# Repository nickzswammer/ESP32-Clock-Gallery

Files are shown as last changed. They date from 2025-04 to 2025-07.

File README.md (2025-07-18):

ESP32

8Ul8SPUI

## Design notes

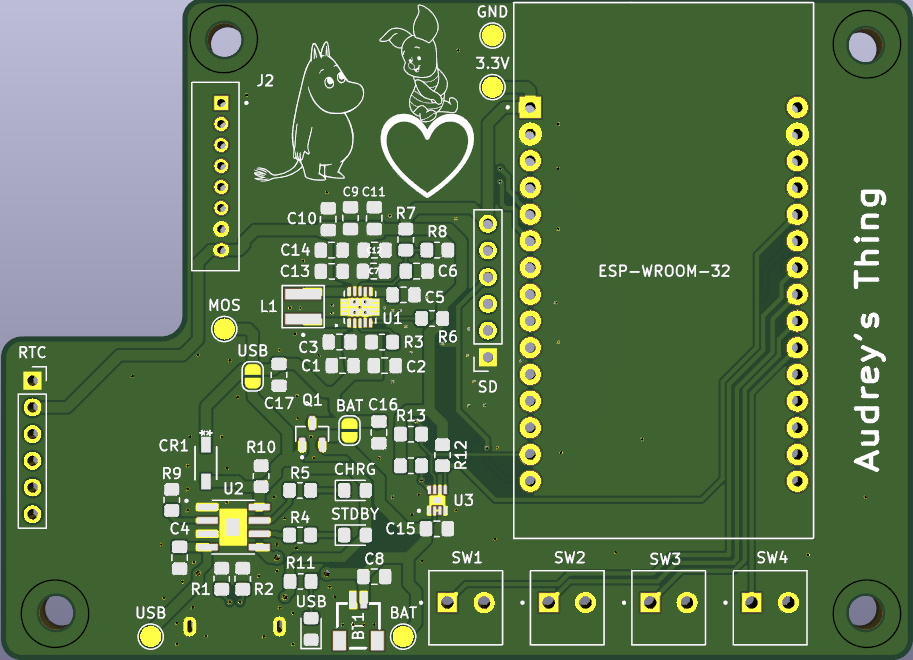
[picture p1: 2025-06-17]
PCB/enclosure/ESP32_Clock_Gallery_topsilkscreen.png

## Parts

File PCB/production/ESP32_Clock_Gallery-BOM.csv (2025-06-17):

Reference | Value | Datasheet | Footprint | Qty | DNP
BT1 | 3.7V 1500mAh LiPo | ~ | SM02B-SRSS-TB_LF__SN_:SM02B-SRSS-TB_LF__SN_ | 1
C1,C2,C4,C8,C9,C10,C11,C12,C13,C14,C16,C17 | 10uF | ~ | Capacitor_SMD:C_0805_2012Metric_Pad1.18x1.45mm_HandSolder | 12
C3,C5,C7,C15 | 0.1uF | ~ | Capacitor_SMD:C_0805_2012Metric_Pad1.18x1.45mm_HandSolder | 4
C6 | 2.2pF | ~ | Capacitor_SMD:C_0805_2012Metric_Pad1.18x1.45mm_HandSolder | 1
CR1 | B5819W-TP | B5819W-TP | B5819SW:SDO_SOD-123_MCC-M | 1
D1,D2,D3 | LED | ~ | LED_SMD:LED_0805_2012Metric_Pad1.15x1.40mm_HandSolder | 3
J1 | UJC-V-G-SMT-P6-TR |  | UJC_V_G_SMT_P6_TR:SAMESKY_UJC-V-G-SMT-P6-TR | 1
J2 | B8B-PH-K-S_LF__SN_ |  | B8B-PH-K-S_LF__SN_:JST_B8B-PH-K-S_LF__SN_ | 1
L1 | 1.2 uH | ~ | XFL4020-102MEC:IND_XFL4020-102MEC | 1
Q1 | PMOS |  | IRLML6402TRPBF:SOT95P237X112-3N | 1
R1,R2 | 5.1K | ~ | Resistor_SMD:R_0805_2012Metric_Pad1.20x1.40mm_HandSolder | 2
R3,R6 | 100K | ~ | Resistor_SMD:R_0805_2012Metric_Pad1.20x1.40mm_HandSolder | 2
R4,R5 | 1K | ~ | Resistor_SMD:R_0805_2012Metric_Pad1.20x1.40mm_HandSolder | 2
R7 | 360K | ~ | Resistor_SMD:R_0805_2012Metric_Pad1.20x1.40mm_HandSolder | 1
R8 | 64.9K | ~ | Resistor_SMD:R_0805_2012Metric_Pad1.20x1.40mm_HandSolder | 1
R9 | 1.5K | ~ | Resistor_SMD:R_0805_2012Metric_Pad1.20x1.40mm_HandSolder | 1
R10,R12 | 10K | ~ | Resistor_SMD:R_0805_2012Metric_Pad1.20x1.40mm_HandSolder | 2
R11 | 470 | ~ | Resistor_SMD:R_0805_2012Metric_Pad1.20x1.40mm_HandSolder | 1
R13,R14 | 4.7K | ~ | Resistor_SMD:R_0805_2012Metric_Pad1.20x1.40mm_HandSolder | 2
SW1,SW2,SW3,SW4 | DB301V-3.5-2P-GN-S | ~ | 1984617:PHOENIX_1984617 | 4
TP1,TP2,TP3,TP4,TP5 | TestPoint | ~ | TestPoint:TestPoint_Pad_D2.0mm | 5
U1 | TPS63060 | http://www.ti.com/lit/ds/symlink/tps63060.pdf | TPS63060DSCT:CONV_TPS63060DSCT | 1
U2 | TP4056 |  | TP4056:SOP127P600X175-9N | 1
U3 | MAX17048G_T10 |  | MAX17048G_T10:SON50P200X200X80-9N | 1
U4 | DS3231 Breakout |  | Connector_PinSocket_2.54mm:PinSocket_1x06_P2.54mm_Vertical | 1
U5 | MicroSD Breakout |  | Connector_PinSocket_2.54mm:PinSocket_1x06_P2.54mm_Vertical | 1
U6 | ESP-WROOM-32 Dev Module |  | ESP32-DEVKIT-V1:MODULE_ESP32_DEVKIT_V1 | 1

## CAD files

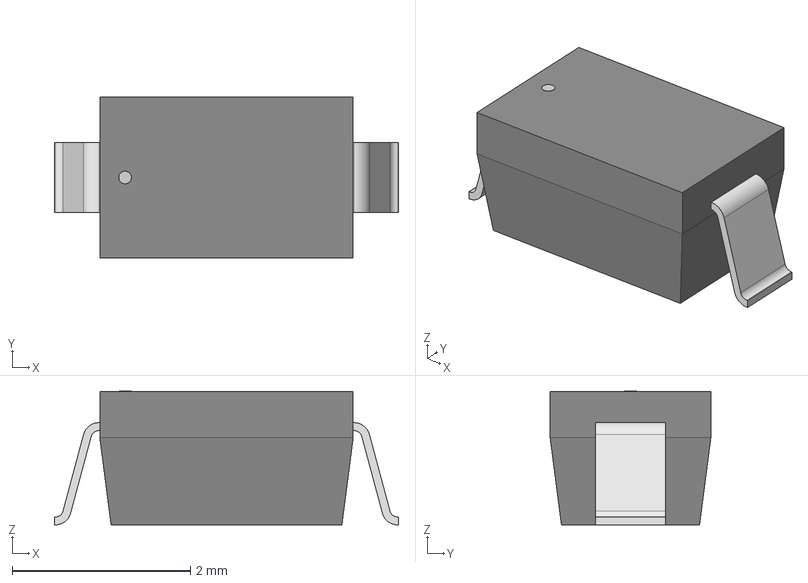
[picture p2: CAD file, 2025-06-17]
PCB/3dmodels/SDO_SOD-123_MCC.step
3.86 x 1.80 x 1.50 mm

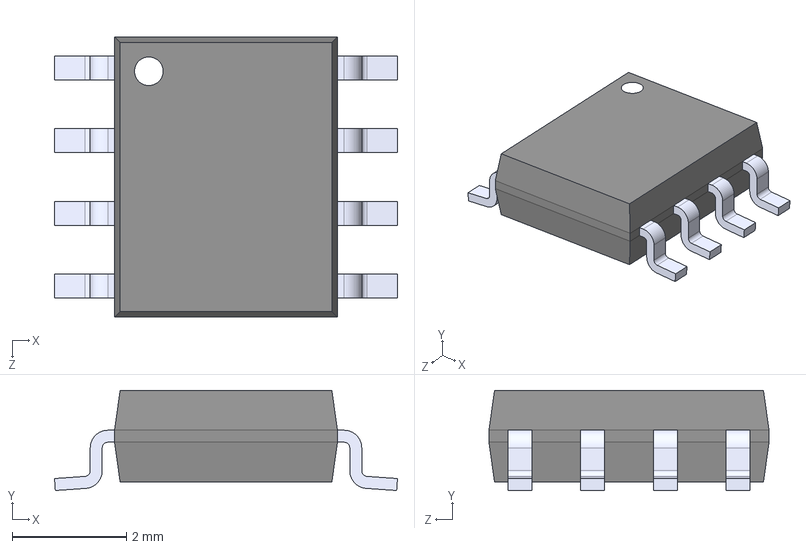
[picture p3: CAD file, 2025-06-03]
PCB/Components/TP4056/TP4056.step
6.00 x 1.75 x 4.90 mm

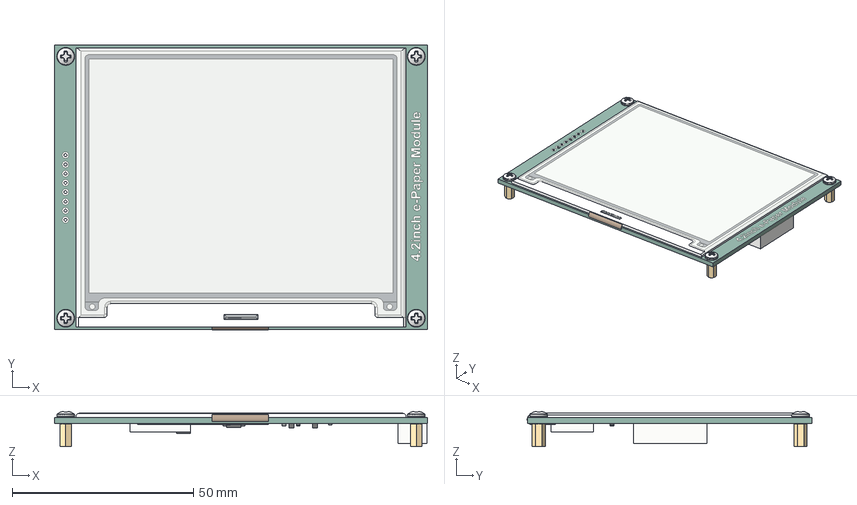
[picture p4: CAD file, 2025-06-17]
PCB/enclosure/Waveshare 4.2inch e-Paper Module.step
103.0 x 78.6 x 9.79 mm
Waveshare 4.2 E-Ink - Display folded cable
PCB
90268A201 x 4
91772A030 x 4

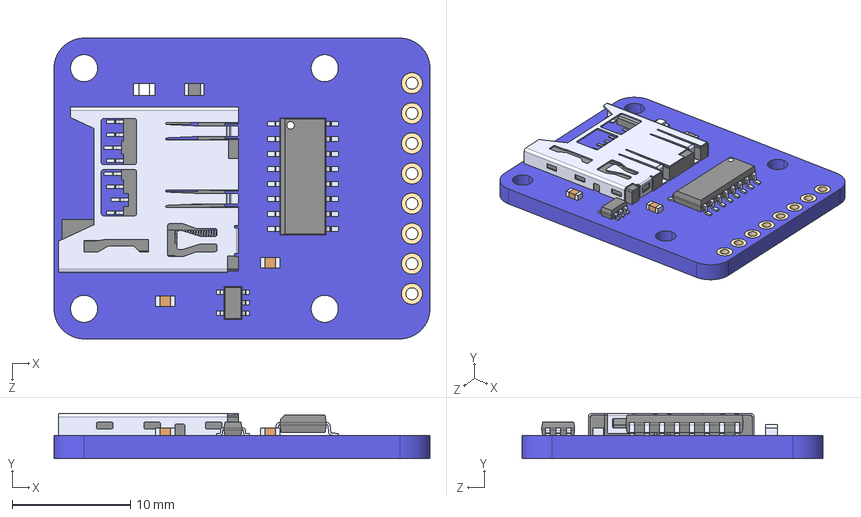
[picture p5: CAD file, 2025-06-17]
PCB/3dmodels/ada_microSD.STEP
31.8 x 3.81 x 25.4 mm

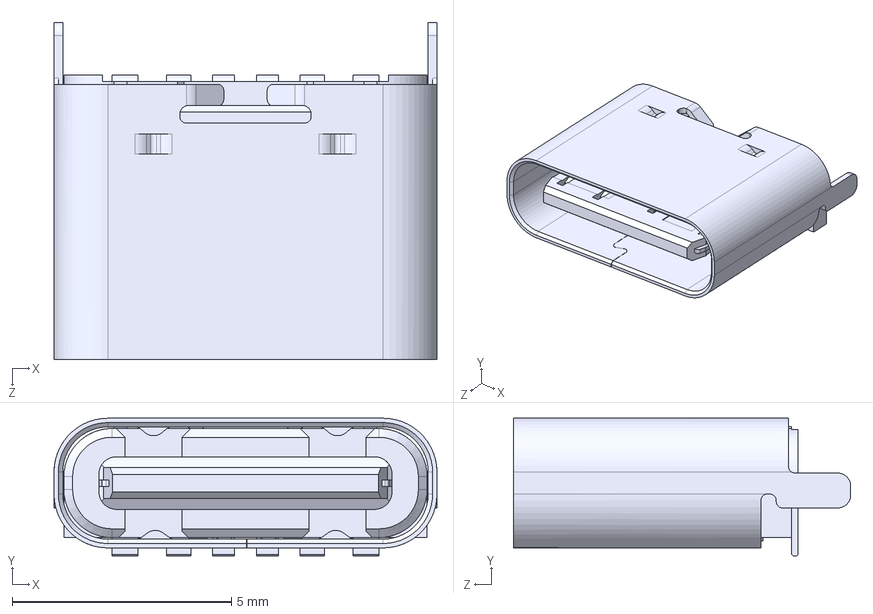
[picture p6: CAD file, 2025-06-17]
PCB/3dmodels/Same_Sky_UJC-V-G-SMT-P6-TR.step
8.74 x 3.14 x 7.70 mm

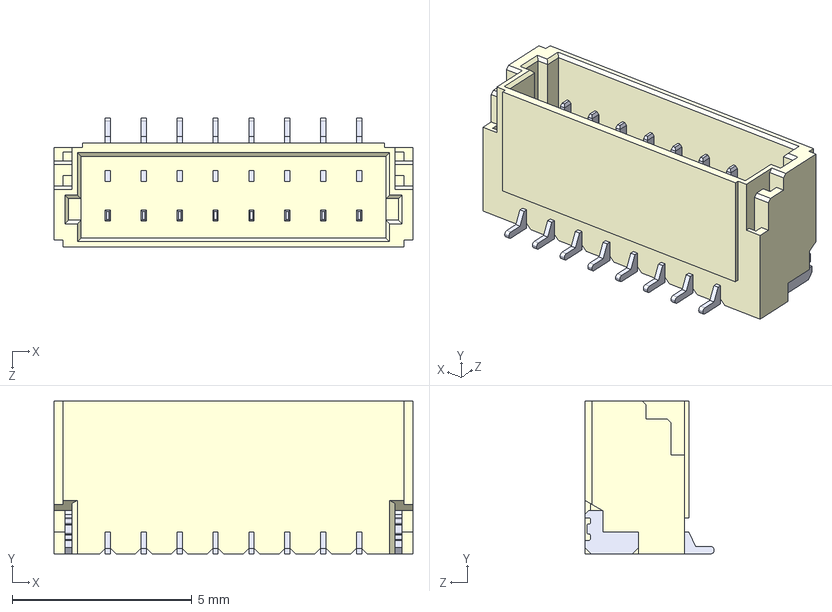
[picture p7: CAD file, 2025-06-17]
PCB/3dmodels/BM08B-SRSS-TB-LF--SN---3DModel-STEP-269445.STEP
10.0 x 4.25 x 3.60 mm

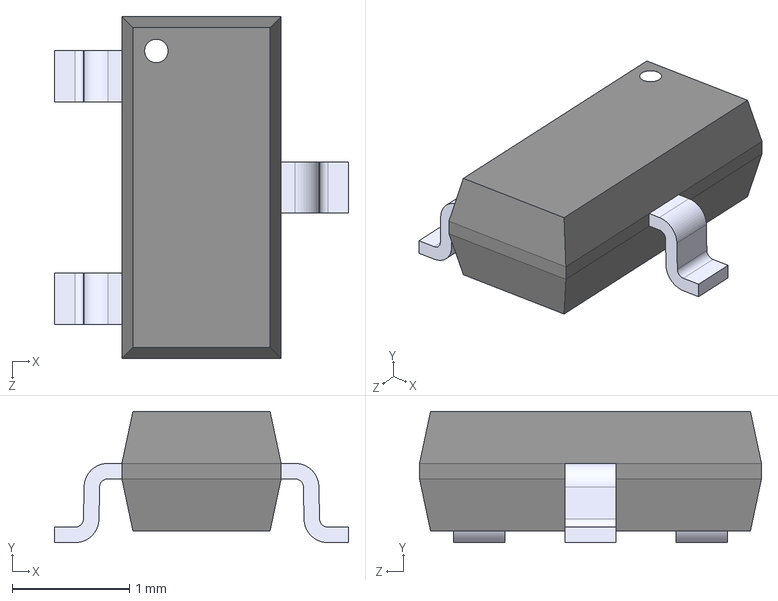
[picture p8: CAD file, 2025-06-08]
PCB/3dmodels/IRLML6402TRPBF.step
2.51 x 1.12 x 2.92 mm

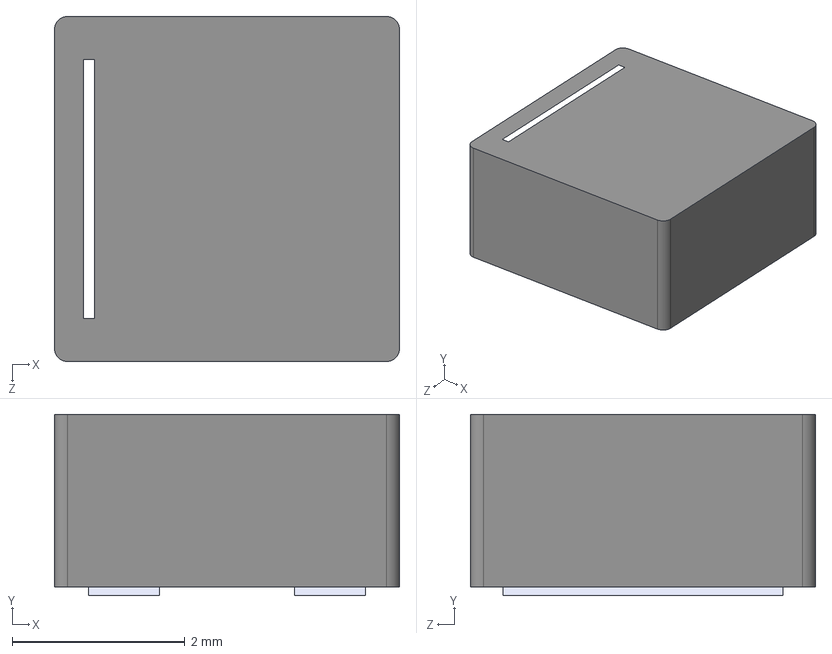
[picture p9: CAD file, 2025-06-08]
PCB/3dmodels/XFL4020-102MEC--3DModel-STEP-269445.STEP
4.00 x 2.10 x 4.00 mm

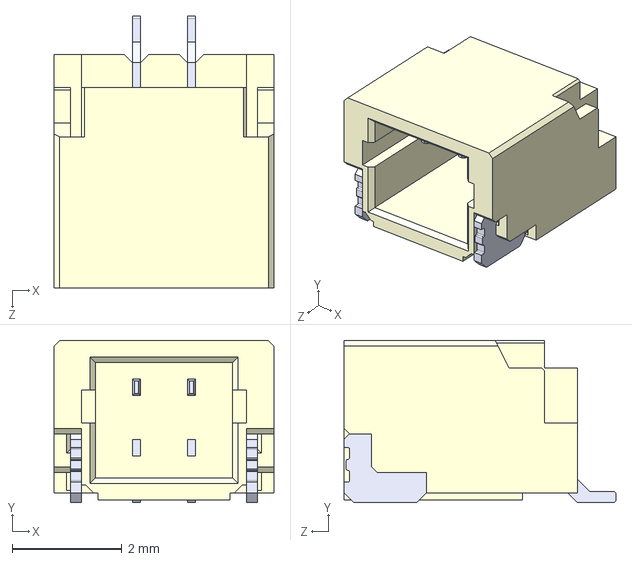
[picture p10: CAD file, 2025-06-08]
PCB/3dmodels/SM02B-SRSS-TB-LF--SN---3DModel-STEP-56544.STEP
4.00 x 2.95 x 4.95 mm

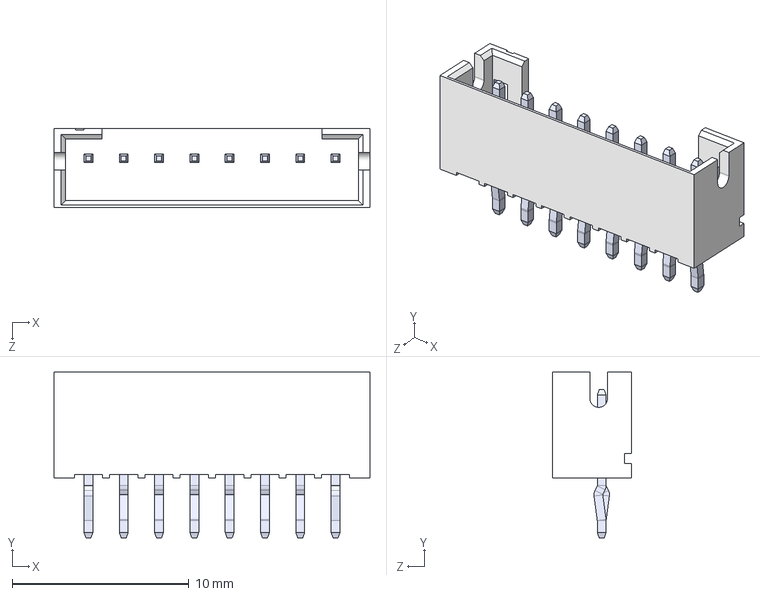
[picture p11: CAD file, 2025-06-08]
PCB/3dmodels/B8B-PH-K-S-LF--SN---3DModel-STEP-56544.STEP
17.9 x 9.40 x 4.50 mm

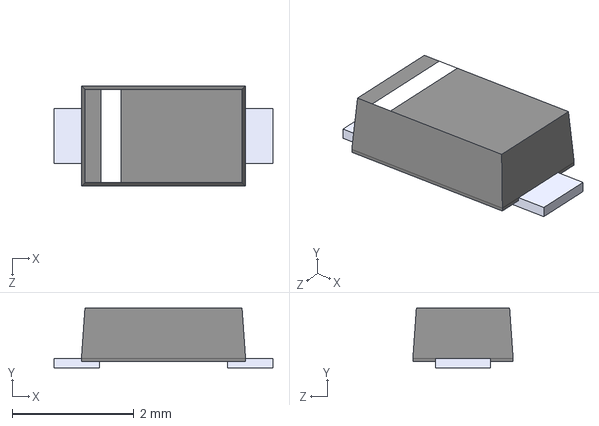
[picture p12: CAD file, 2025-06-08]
PCB/3dmodels/MBR120VLSFT1G.step
3.60 x 0.98 x 1.65 mm

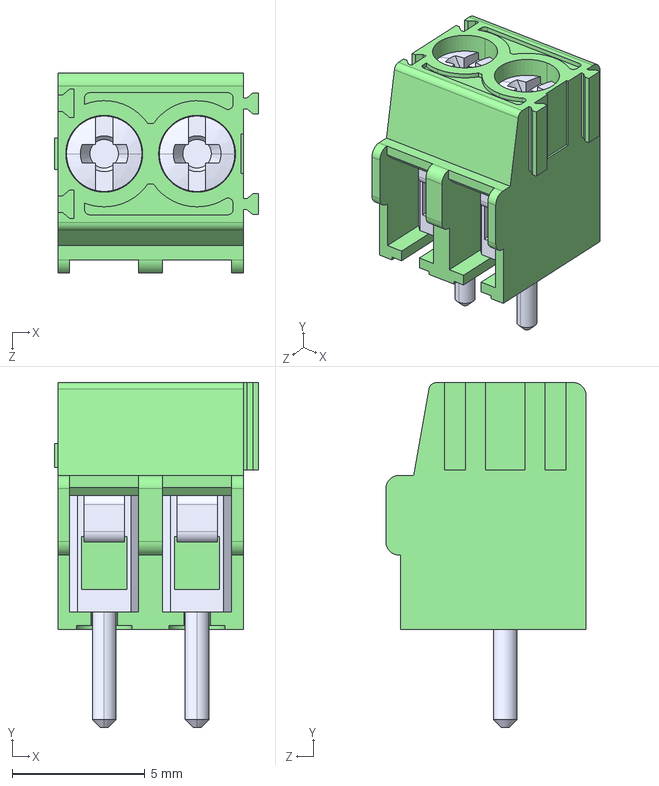
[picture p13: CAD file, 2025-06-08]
PCB/Components/1984617/1984617.step
7.70 x 13.0 x 7.55 mm

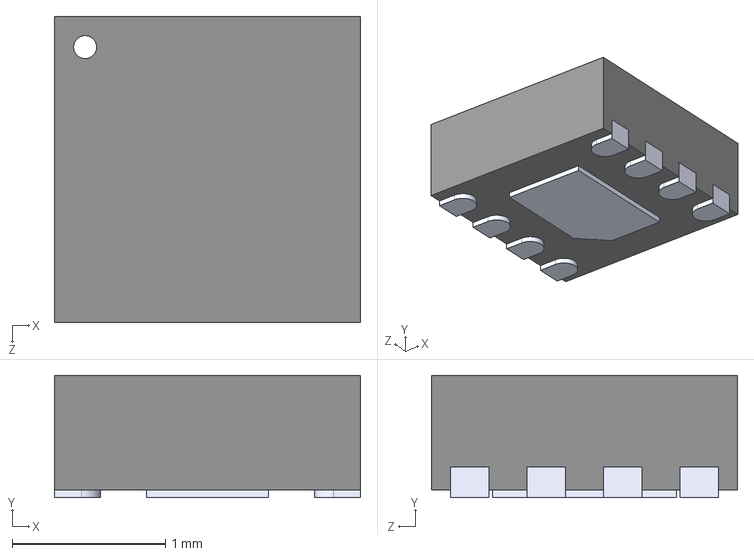
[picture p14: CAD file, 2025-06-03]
PCB/Components/MAX17048G_T10/MAX17048G_T10.step
2.00 x 0.8 x 2.00 mm

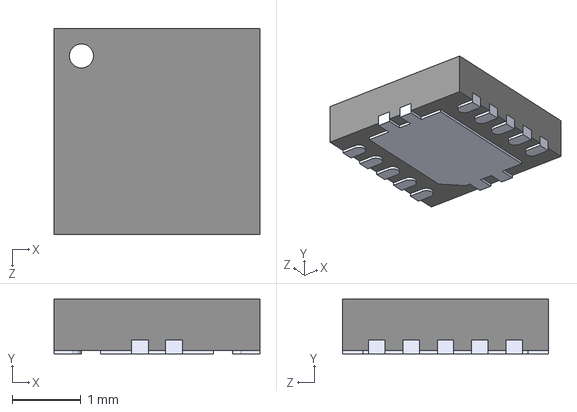
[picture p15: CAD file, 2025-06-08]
PCB/3dmodels/TPS63060DSCT.STEP
3.00 x 0.8 x 3.00 mm

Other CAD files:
PCB/3dmodels/XAL4020122ME--3DModel-STEP-56544.STEP

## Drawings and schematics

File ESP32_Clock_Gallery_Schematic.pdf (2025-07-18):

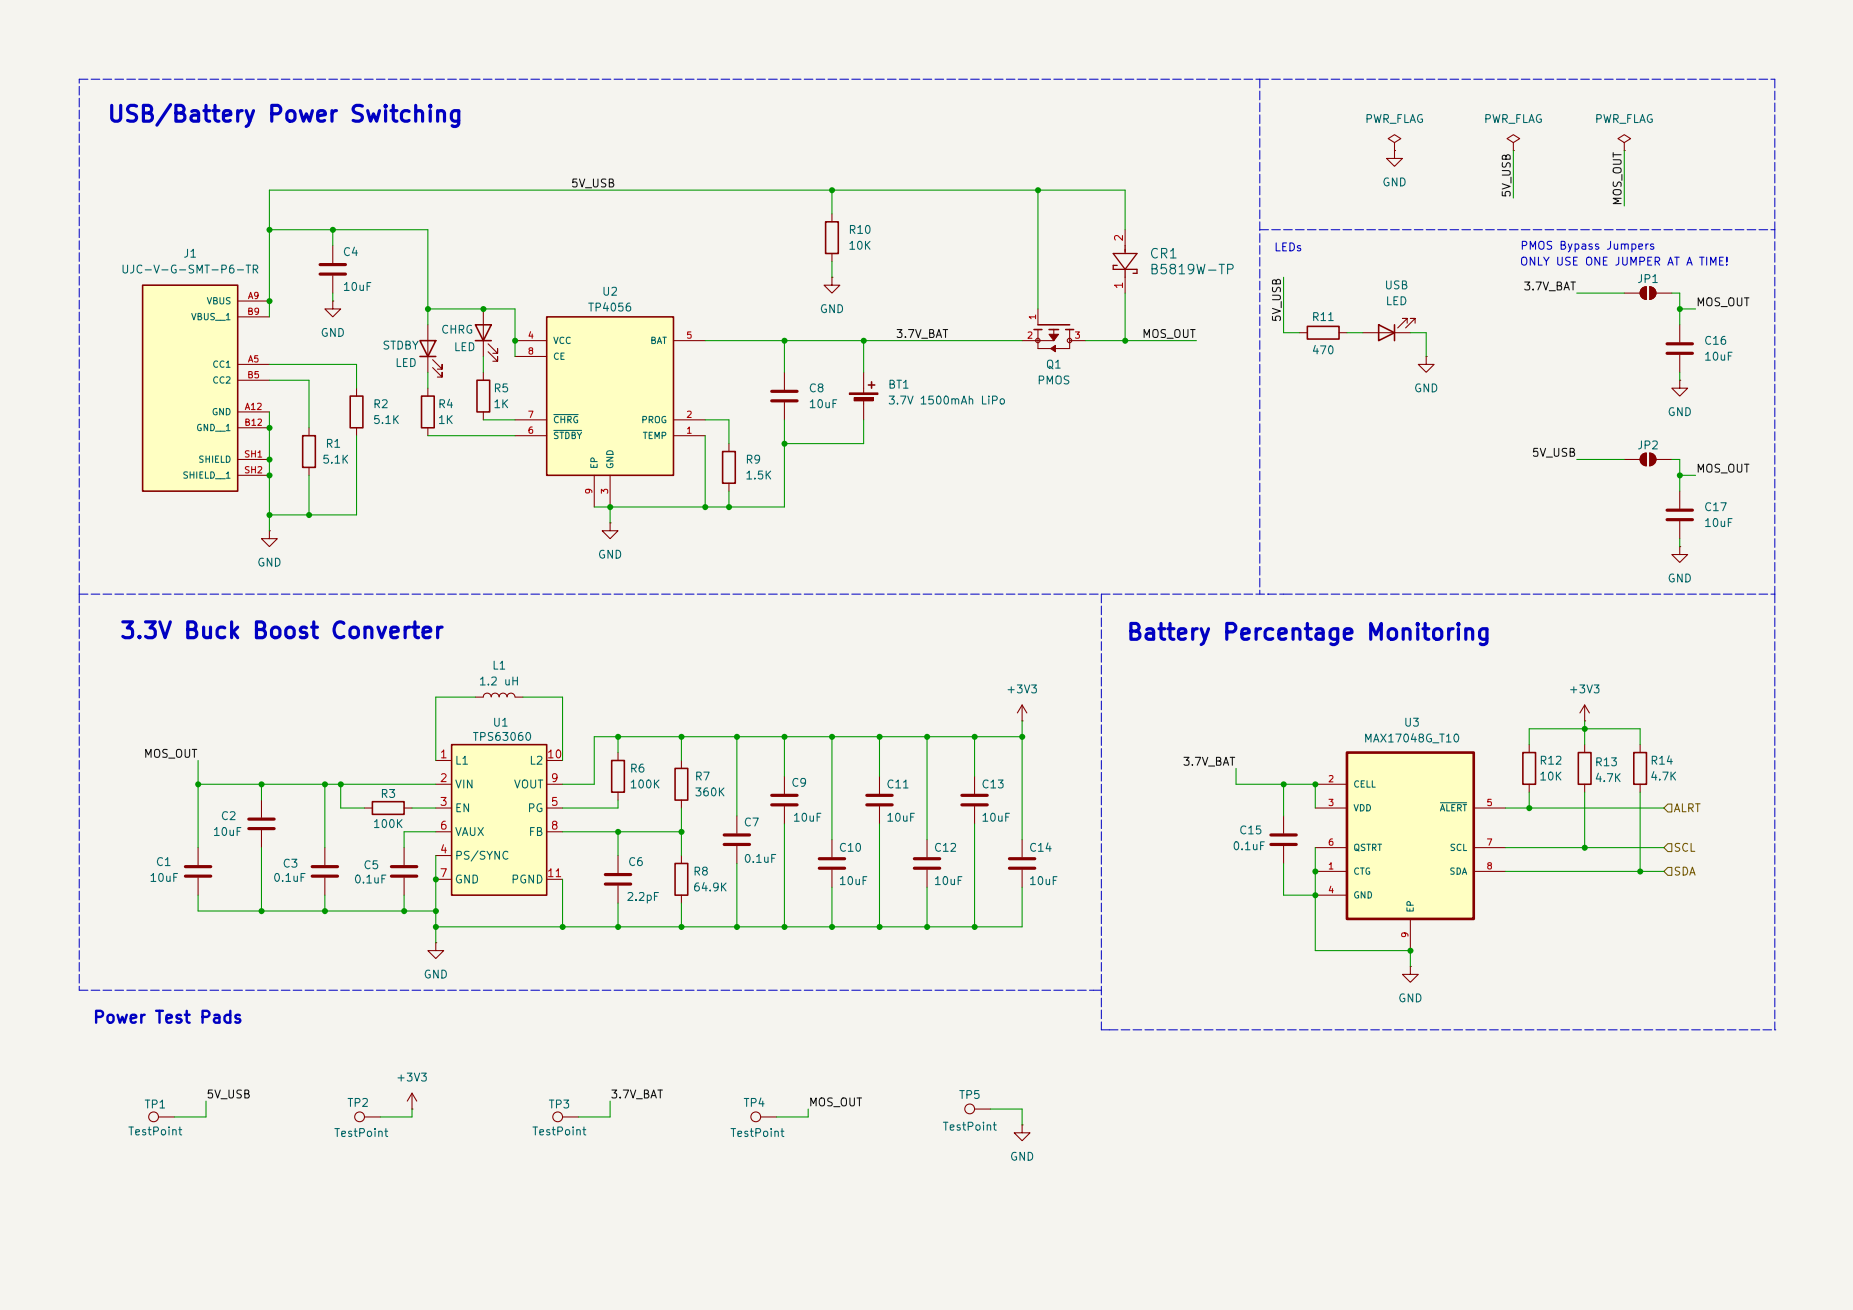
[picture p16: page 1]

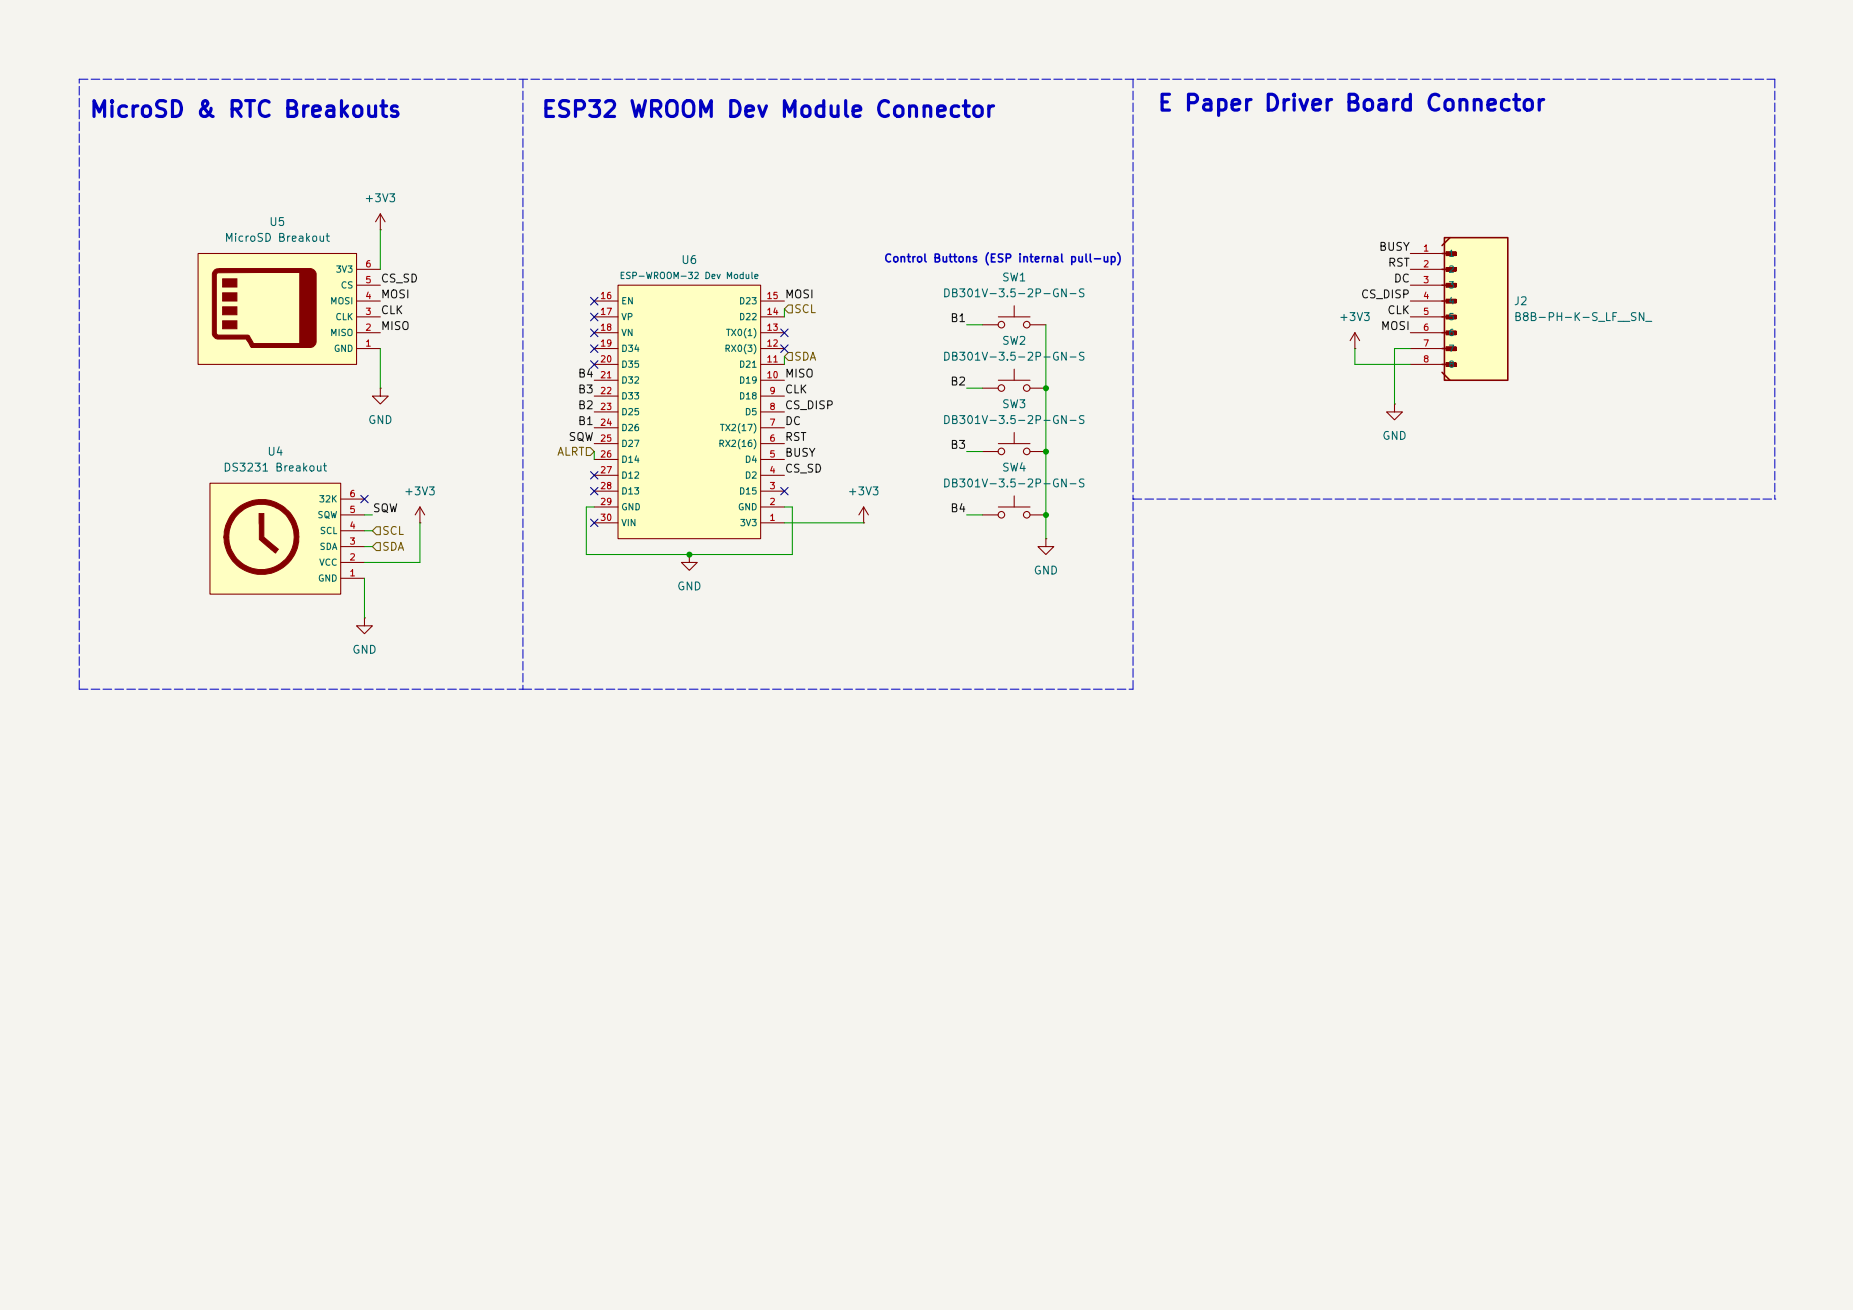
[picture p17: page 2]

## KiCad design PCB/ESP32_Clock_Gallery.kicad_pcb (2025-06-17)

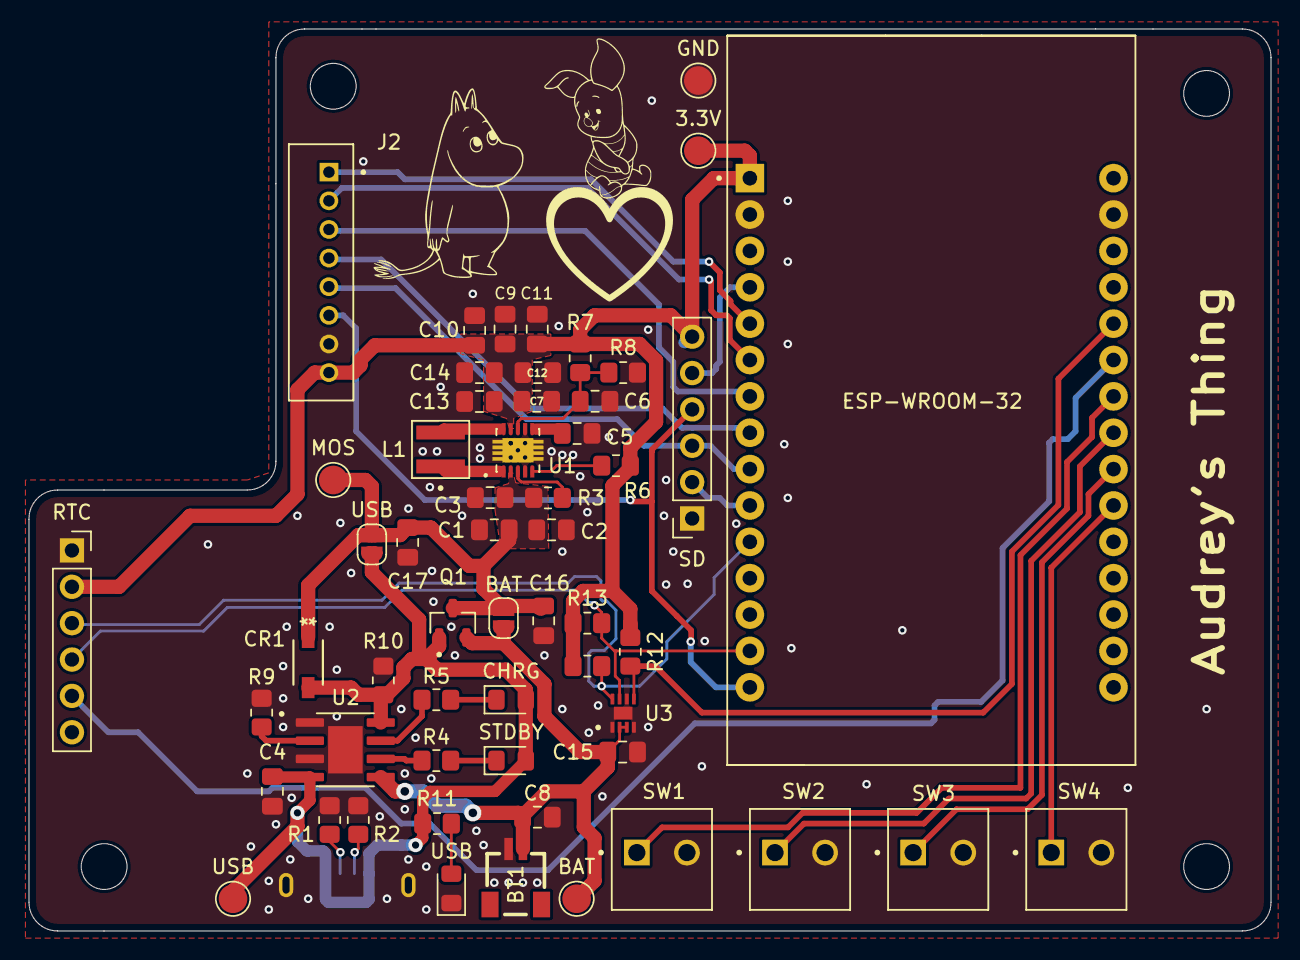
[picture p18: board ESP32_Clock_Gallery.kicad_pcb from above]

Board: 2 copper layers, 86.8 x 63.0 mm, 57 parts (1 on the bottom side), 35 nets.

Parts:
3.3V: TestPoint; TestPoint_Pad_D2.0mm
BAT: SolderJumper_2_Open; SolderJumper-2_P1.3mm_Open_RoundedPad1.0x1.5mm
BAT#2: TestPoint; TestPoint_Pad_D2.0mm
BT1: 3.7V 1500mAh LiPo; SM02B-SRSS-TB_LF__SN_
C1, C2, C4, C8, C9, C10, C11, C12, C13, C14, C16, C17: 10uF; C_0805_2012Metric_Pad1.18x1.45mm_HandSolder
C3, C5, C7, C15: 0.1uF; C_0805_2012Metric_Pad1.18x1.45mm_HandSolder
C6: 2.2pF; C_0805_2012Metric_Pad1.18x1.45mm_HandSolder
CHRG: LED; LED_0805_2012Metric_Pad1.15x1.40mm_HandSolder
CR1: B5819W-TP; SDO_SOD-123_MCC-M
ESP-WROOM-32: ESP-WROOM-32 Dev Module; MODULE_ESP32_DEVKIT_V1
GND: TestPoint; TestPoint_Pad_D2.0mm
J1: UJC-V-G-SMT-P6-TR; SAMESKY_UJC-V-G-SMT-P6-TR
J2: B8B-PH-K-S_LF__SN_; JST_B8B-PH-K-S_LF__SN_
L1: 1.2 uH; IND_XFL4020-102MEC
MOS: TestPoint; TestPoint_Pad_D2.0mm
Q1: PMOS; SOT95P237X112-3N
R1, R2: 5.1K; R_0805_2012Metric_Pad1.20x1.40mm_HandSolder
R3, R6: 100K; R_0805_2012Metric_Pad1.20x1.40mm_HandSolder
R4, R5: 1K; R_0805_2012Metric_Pad1.20x1.40mm_HandSolder
R7: 360K; R_0805_2012Metric_Pad1.20x1.40mm_HandSolder
R8: 64.9K; R_0805_2012Metric_Pad1.20x1.40mm_HandSolder
R9: 1.5K; R_0805_2012Metric_Pad1.20x1.40mm_HandSolder
R10, R12: 10K; R_0805_2012Metric_Pad1.20x1.40mm_HandSolder
R11: 470; R_0805_2012Metric_Pad1.20x1.40mm_HandSolder
R13, R14: 4.7K; R_0805_2012Metric_Pad1.20x1.40mm_HandSolder
RTC: DS3231 Breakout; PinSocket_1x06_P2.54mm_Vertical
SD: MicroSD Breakout; PinSocket_1x06_P2.54mm_Vertical
STDBY: LED; LED_0805_2012Metric_Pad1.15x1.40mm_HandSolder
SW1, SW2, SW3, SW4: DB301V-3.5-2P-GN-S; PHOENIX_1984617
U1: TPS63060; CONV_TPS63060DSCT
U2: TP4056; SOP127P600X175-9N
U3: MAX17048G_T10; SON50P200X200X80-9N
USB: SolderJumper_2_Open; SolderJumper-2_P1.3mm_Open_RoundedPad1.0x1.5mm
USB#2: TestPoint; TestPoint_Pad_D2.0mm
USB#3: LED; LED_0805_2012Metric_Pad1.15x1.40mm_HandSolder

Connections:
+3V3: 3.3V.1, C7.1, C9.1, C10.1, C11.1, C12.1, C13.1, C14.1, ESP-WROOM-32.1 (3V3), J2.8, R6.1, R7.1, R12.1, R13.1, R14.1, RTC.2 (VCC), SD.6 (3V3), U1.9 (VOUT)
/ESP32/ALRT: ESP-WROOM-32.26 (D14), R12.2, U3.5 (~ALERT)
/ESP32/B1: ESP-WROOM-32.24 (D26), SW1.1
/ESP32/B2: ESP-WROOM-32.23 (D25), SW2.1
/ESP32/B3: ESP-WROOM-32.22 (D33), SW3.1
/ESP32/B4: ESP-WROOM-32.21 (D32), SW4.1
/ESP32/BUSY: ESP-WROOM-32.5 (D4), J2.1
/ESP32/CLK: ESP-WROOM-32.9 (D18), J2.5, SD.3 (CLK)
/ESP32/CS_DISP: ESP-WROOM-32.8 (D5), J2.4
/ESP32/CS_SD: ESP-WROOM-32.4 (D2), SD.5 (CS)
/ESP32/DC: ESP-WROOM-32.7 (TX2(17)), J2.3
/ESP32/MISO: ESP-WROOM-32.10 (D19), SD.2 (MISO)
/ESP32/MOSI: ESP-WROOM-32.15 (D23), J2.6, SD.4 (MOSI)
/ESP32/RST: ESP-WROOM-32.6 (RX2(16)), J2.2
/ESP32/SCL: ESP-WROOM-32.14 (D22), R13.2, RTC.4 (SCL), U3.7 (SCL)
/ESP32/SDA: ESP-WROOM-32.11 (D21), R14.2, RTC.3 (SDA), U3.8 (SDA)
/ESP32/SQW: ESP-WROOM-32.25 (D27), RTC.5 (SQW)
/Power/3.7V_BAT: BAT.1 (A), BAT#2.1, BT1.2 (-), C8.1, C15.1, Q1.2, U2.5 (BAT), U3.2 (CELL), U3.3 (VDD)
/Power/5V_USB: C4.1, CHRG.2 (A), CR1.2, J1.A9 (VBUS), J1.B9 (VBUS__1), Q1.1, R10.1, R11.2, STDBY.2 (A), U2.4 (VCC), U2.8 (CE), USB.1 (A), USB#2.1
/Power/MOS_OUT: BAT.2 (B), C1.1, C2.1, C3.1, C16.1, C17.1, CR1.1, MOS.1, Q1.3, R3.1, U1.2 (VIN), USB.2 (B)
GND: BT1.1 (+), C1.2, C2.2, C3.2, C4.2, C5.2, C6.2, C7.2, C8.2, C9.2, C10.2, C11.2, C12.2, C13.2, C14.2, C15.2, C16.2, C17.2, ESP-WROOM-32.2 (GND), ESP-WROOM-32.29 (GND), GND.1, J1.A12 (GND), J1.B12 (GND__1), J1.SH1 (SHIELD), J1.SH2 (SHIELD__1), J2.7, R1.1, R2.1, R8.2, R9.1, R10.2, RTC.1 (GND), SD.1 (GND), SW1.2, SW2.2, SW3.2, SW4.2, U1.4 (PS/SYNC), U1.7 (GND), U1.11 (PGND), U1.12, U1.13, U1.14, U1.15, U1.16, U2.1 (TEMP), U2.3 (GND), U2.9 (EP), U3.1 (CTG), U3.4 (GND), U3.6 (QSTRT), U3.9 (EP), USB#3.1 (K)
unnamed: R4.2, STDBY.1 (K)
unnamed: CHRG.1 (K), R5.2
unnamed: R11.1, USB#3.2 (A)
unnamed: J1.A5 (CC1), R2.2
unnamed: J1.B5 (CC2), R1.2
unnamed: R3.2, U1.3 (EN)
unnamed: C6.1, R7.2, R8.1, U1.8 (FB)
unnamed: L1.1, U1.1 (L1)
unnamed: L1.2, U1.10 (L2)
unnamed: R6.2, U1.5 (PG)
unnamed: C5.1, U1.6 (VAUX)
unnamed: R9.2, U2.2 (PROG)
unnamed: R5.1, U2.7 (~CHRG)
unnamed: R4.1, U2.6 (~STDBY)

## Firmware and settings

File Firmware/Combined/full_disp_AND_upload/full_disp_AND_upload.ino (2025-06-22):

/*
  Project Title: Audrey Clock Gallery
  File Name:     full_disp_AND_upload.ino
  Author:        Nicholas Zhang
  Date:          May 16, 2025

  Description:
  4 Pushbuttons and gives user interface to select files to display and clock, as well as enabling SD Wifi Uploading
*/

/* ========================== LIBRARIES & FILES ========================== */

#include <GxEPD2_BW.h>
#include "GxEPD2_display_selection_new_style.h"
#include <Fonts/FreeSansBold24pt7b.h>
#include <Fonts/FreeSansBold12pt7b.h>
#include <Fonts/FreeSans9pt7b.h>
#include <MAX17043.h>

// Wifi Libraries
#include <WiFi.h>            //Built-in
#include <ESP32WebServer.h>  //https://github.com/Pedroalbuquerque/ESP32WebServer download and place in your Libraries folder
#include "esp_wifi.h"

// SD Libraries
#include "FS.h"
#include "SD.h"
#include "SPI.h"

// RTC Library Include
#include "RTClib.h"

// Long Button Press
#include "OneButton.h"

// Local Headers
#include "WebHelpers.h"  //Includes headers of the web and style file
#include "AppState.h"
#include "secrets.h"

// pin definitions
#define CS_SD 2
#define BUTTON_1 26
#define BUTTON_2 25
#define BUTTON_3 33
#define BUTTON_4 32
#define ALRT 26

#define LONG_PRESS_TIME 1500       // milliseconds
#define uS_TO_S_FACTOR 1000000ULL  // 1e06

#define MENU_ITEMS 3

#define DIRECTORY "/bin_images"

AppState app;

/* ========================== VARIABLES ========================== */

ESP32WebServer server(80);
RTC_DS3231 rtc;

String formattedTimeArray[5] = { "Tuesday, May 29, 2025", "Tuesday", "11", "59", "AM" };

char daysOfTheWeek[7][12] = { "Sunday", "Monday", "Tuesday", "Wednesday", "Thursday", "Friday", "Saturday" };
char months[12][4] = {
  "Jan", "Feb", "Mar", "Apr", "May", "Jun",
  "Jul", "Aug", "Sep", "Oct", "Nov", "Dec"
};

// for long button presses (B1 & B4)
unsigned long button1PressTime = 0;
bool button1Held = false;

unsigned long button4PressTime = 0;
bool button4Held = false;

String lastDisplayedTime = "";

// clockvars for update clock stuff
String currentTime;
DateTime now;
uint8_t batteryPercentage;


uint8_t menu_selected_index = 0;

uint64_t uploadedGalleryInterval = 10ULL * uS_TO_S_FACTOR;  // default is 10 seconds until user sets (IN MICROSECONDS)
                                                            // ULL prevents overflow so it is an unsigned long long

bool device_mode = 0;  // 0 is clock, 1 is display
bool menu = 0;         // 0 is menu off, 1 is menu on
bool sleeping = 0;     // 0 is not sleeping, 1 is yes, to handle wake ups

/* ========================== SETUP ========================== */

void setup() {
  Serial.begin(115200);
  delay(250);

  while (!Serial) {}
  Serial.println("Serial port initialized.\n");

  display.init(115200);
  display.setRotation(2);
  display.setFullWindow();

  pinMode(BUTTON_1, INPUT_PULLUP);
  pinMode(BUTTON_2, INPUT_PULLUP);
  pinMode(BUTTON_3, INPUT_PULLUP);
  pinMode(BUTTON_4, INPUT_PULLUP);
  pinMode(ALRT, INPUT_PULLUP);

  /* ===================== WIFI BLOCK ===================== */
  restartWiFiAndServer();

  /* ===================== INIT SD CARD ===================== */
  Serial.print(F("Initializing SD card... "));

  //see if the card is present and can be initialised.
  if (!SD.begin(CS_SD)) {
    Serial.println(F("Card failed or not present, no SD Card data logging possible..."));
    app.sdPresent = false;
  } else {
    Serial.println(F("\nCard initialised. File access enabled!"));
    app.sdPresent = true;
  }

  // starts off directory inside /bin_images
  app.root = SD.open(DIRECTORY);
  if (!app.root || !app.root.isDirectory()) {
    Serial.println("ERROR: Failed to open directory");
    return;
  }

  app.currentFile = app.root.openNextFile();
  app.currentFileName = getCurrentFileName();
  app.fileNames[0][0] = getCurrentFileName();

  list_dir(SD, DIRECTORY);

  /* ===================== INIT RTC ===================== */
  if (!rtc.begin()) {
    Serial.println("Couldn't find RTC");
    Serial.flush();
  }

  if (rtc.lostPower()) {
    Serial.println("RTC lost power, let's set the time!");
    // When time needs to be set on a new device, or after a power loss, the
    // following line sets the RTC to the date & time this sketch was compiled
    rtc.adjust(DateTime(F(__DATE__), F(__TIME__)));
    // This line sets the RTC with an explicit date & time, for example to set
    // January 21, 2014 at 3am you would call:
    //rtc.adjust(DateTime(2014, 1, 21, 3, 0, 0));
  }

  /* ===================== INIT FUEL GUAGE ===================== */
  // Initialize the fuel gauge.
  //
  if (FuelGauge.begin()) {
    //
    // Reset the device.
    //
    Serial.println("Resetting device...");
    FuelGauge.reset();
    delay(250);

    //
    // Issue a quickstart command and wait
    // for the device to be ready.
    //
    Serial.println("Initiating quickstart mode...");
    FuelGauge.quickstart();
    delay(125);

    //
    // Display an initial reading.
    //
    Serial.println("Reading device...");
    Serial.println();
    Serial.printf("Battery Percentage: %d\n", FuelGauge.percent());
    
    FuelGauge.setThreshold(10); // set low battery threshold to 10%

  } else {
    Serial.println("The MAX17043 device was NOT found.\n");
  }
}

void loop() {
  // button states
  app.currButton1 = digitalRead(BUTTON_1);
  app.currButton2 = digitalRead(BUTTON_2);
  app.currButton3 = digitalRead(BUTTON_3);
  app.currButton4 = digitalRead(BUTTON_4);

  // updates formatted time array with current RTC readings, also updates battery percentage
  updateClock();

  // if alert, just display low battery
  if (FuelGauge.alertIsActive())
  {
    display.firstPage();
    do {
      display.fillScreen(GxEPD_WHITE);  // clear the display
      display.setTextColor(GxEPD_BLACK);
      display.setFont(&FreeSansBold24pt7b);
      display.setTextSize(3);

      display.setCursor(20, 50);  // starting position (x,y)
      display.print("CHARGE! LOW BATTERY");

    } while (display.nextPage());

    Serial.println("entering low power mode");
    
    while (true) 
    {
      constexpr gpio_num_t WAKEUP_PIN = GPIO_NUM_26;        // button 1
      gpio_wakeup_enable(WAKEUP_PIN, GPIO_INTR_LOW_LEVEL);  // Trigger wake-up on high level

      esp_sleep_enable_gpio_wakeup();

      // Stop server and Wi-Fi
      Serial.println("Turning off WiFi...");
      stopWifi();
      Serial.println("WiFi Disabled.");

      // sleep
      Serial.println("Now Sleeping.");
      delay(500);
      esp_light_sleep_start();

      // After waking
      Serial.println("Woke up!");
      esp_sleep_wakeup_cause_t wakeup_reason = esp_sleep_get_wakeup_cause();

      if (wakeup_reason == ESP_SLEEP_WAKEUP_GPIO) {
        Serial.println("Button Wake Detected — exiting sleep loop");
        menu = 0;
        device_mode = 0;

        displayClock(currentTime, formattedTimeArray[0], batteryPercentage, 0);

        // restart wifi
        Serial.println("Restarting Wifi...");
        restartWiFiAndServer();
        Serial.println("Restarting Wifi completed.");

        delay(1000); 

        break;  // Exit the while(true)
      }
    }
  }

  // update clock once minute changes in RTC
  if (currentTime != lastDisplayedTime && !device_mode && !menu) {
    lastDisplayedTime = currentTime;  // update the stored time

    displayClock(currentTime, formattedTimeArray[0], batteryPercentage, 0);
  }

  //Serial.printf("\nCurrent Formatted Time: %s\n", formatTime(now).c_str());
  //Serial.printf("\nCurrent Time: %s:%s %s\n", formattedTimeArray[2], formattedTimeArray[3], formattedTimeArray[4]);

  //Listen for client connections
  server.handleClient();

  // set file name
  app.currentFileName = getCurrentFileName();

  // display
  // display curr file or toggle menu (TOGGLED ON LONG PRESS)

  // detects button press
  if (!app.currButton1 && app.prevButton1) {
    button1PressTime = millis();
    button1Held = false;
  }

  if (!app.currButton1 && (millis() - button1PressTime > LONG_PRESS_TIME)) {
    if (!button1Held) {
      button1Held = true;
      Serial.println("Long Press For Button 1 Detected: Toggle Menu");
      menu = !menu;

      Serial.print("Menu is now ");
      Serial.println(menu ? "Showing" : "Not Showing");
      menu ? displayMenu() : displayClock(currentTime, formattedTimeArray[0], batteryPercentage, 0);

      // also change device mode to clock if menu is not showing
      device_mode = menu ? 1 : 0;
      Serial.println(device_mode ? "" : "Device is now in Clock Mode");
    }
  }

  // regular short press behavior
  if (app.wasPressed(app.currButton1, app.prevButton1)) {
    if (!button1Held && device_mode && !menu)
      handle_button_1();
  }

  // select prev file
  if (app.wasPressed(app.currButton2, app.prevButton2 && device_mode && !menu)) {
    list_dir(SD, DIRECTORY);

    Serial.println("");

    if (app.fileCount == 0) {
      Serial.println("No files found");
      return;
    }

    if (app.fileMode) {
      app.currentFileIndex--;

      if (app.currentFileIndex < 0)
        app.currentFileIndex = app.fileCount - 1;

      Serial.printf("Selected File Index: [%d]: ", app.currentFileIndex);
    } else {
      // PAGE SELECT MODE: move to previous page
      uint8_t currentPage = getCurrentPage();
      currentPage = (currentPage - 1 + app.totalPages) % app.totalPages;

      app.currentFileIndex = currentPage * MAX_FILES_PER_PAGE;

      Serial.printf("Selected Page Number: #%d\n", currentPage + 1);
    }
    Serial.println(String(app.currentFileIndex + 1) + " " + getCurrentFileName());
    display_files();
  }

  // if menu open, select prev thing
  else if (app.wasPressed(app.currButton2, app.prevButton2 && menu)) {
    menu_selected_index = (menu_selected_index - 1 + MENU_ITEMS) % MENU_ITEMS;
    displayMenu();
  }

  // select next file
  if (app.wasPressed(app.currButton3, app.prevButton3) && device_mode && !menu) {
    list_dir(SD, DIRECTORY);

    Serial.println("");

    if (app.fileCount == 0) {
      Serial.println("No files found");
      return;
    }

    // FILE SELECT MODE: move onto next image to display
    if (app.fileMode) {
      app.currentFileIndex++;

      if (app.currentFileIndex > app.fileCount - 1)
        app.currentFileIndex = 0;

      Serial.printf("Selected File Number: #[%d]: ", app.currentFileIndex);
    } else {
      // PAGE SELECT MODE: move to next page
      uint8_t currentPage = getCurrentPage();
      currentPage = (currentPage + 1 + app.totalPages) % app.totalPages;
      app.currentFileIndex = currentPage * MAX_FILES_PER_PAGE;

      Serial.printf("Selected Page Number: #%d\n", currentPage + 1);
    }
    Serial.println(String(app.currentFileIndex + 1) + " " + getCurrentFileName());

    display_files();
  }

  // if menu open, select prev thing
  else if (app.wasPressed(app.currButton3, app.prevButton3 && menu)) {
    menu_selected_index = (menu_selected_index + 1) % MENU_ITEMS;
    displayMenu();
  }

  // show files OR go to clock mode (TOGGLED ON LONG PRESS)

  // detects button press
  if (!app.currButton4 && app.prevButton4) {
    button4PressTime = millis();
    button4Held = false;
  }

  if (!app.currButton4 && (millis() - button4PressTime > LONG_PRESS_TIME)) {
    if (!button4Held && !menu) {
      button4Held = true;
      Serial.println("Long Press Detected: Change Modes");
      device_mode = !device_mode;

      Serial.print("Device is now in ");
      Serial.println(device_mode ? "Display Mode" : "Clock Mode");
      device_mode ? display_files() : displayClock(currentTime, formattedTimeArray[0], batteryPercentage, 0);
    }
  }

  if (app.wasPressed(app.currButton4, app.prevButton4)) {
    if (!button4Held && device_mode && !menu) {
      app.fileMode = !app.fileMode;
      if (app.fileMode) {
        Serial.println("Changed to File Select Mode");
      } else {
        Serial.println("Changed to Page Select Mode");
      }
      display_files();
    }
    // if in menu, handle sleep
    // menu_selected_index: (0/1 for Sleep Modes, 2 for hibernation (ONLY DISPLAY ONE IMAGE))
    else if (!button4Held && menu) {
      Serial.printf("Button 4 In Menu Press Detected for: %d\n", menu_selected_index);
      // sleep but show gallery and rotate every uploadedGalleryInterval
      if (menu_selected_index == 0) {
        Serial.println("In Sleep Mode, displaying gallery");
        while (true) {
          constexpr gpio_num_t WAKEUP_PIN = GPIO_NUM_26;        // button 1
          gpio_wakeup_enable(WAKEUP_PIN, GPIO_INTR_LOW_LEVEL);  // Trigger wake-up on high level

          esp_sleep_enable_gpio_wakeup();
          esp_sleep_enable_timer_wakeup(uploadedGalleryInterval);

          // Stop server and Wi-Fi
          Serial.println("Turning off WiFi...");
          stopWifi();
          Serial.println("WiFi Disabled.");

          list_dir(SD, DIRECTORY);

          Serial.printf("Selected File Number: #[%d]: ", app.currentFileIndex);
          Serial.printf("Printing Current File: %s [%d]\n", getCurrentFileName(), app.currentFileIndex);
          String current_file_location = String(DIRECTORY) + "/" + getCurrentFileName();
          app.currentFile = SD.open(current_file_location, FILE_READ);
          displayImageFromBin(app.currentFile);

          // select next file
          app.currentFileIndex++;

          // wrap around
          if (app.currentFileIndex > app.fileCount - 1)
            app.currentFileIndex = 0;

          // sleep
          Serial.println("Now Sleeping.");
          delay(500);
          esp_light_sleep_start();

          // After waking
          Serial.println("Woke up!");
          esp_sleep_wakeup_cause_t wakeup_reason = esp_sleep_get_wakeup_cause();

          if (wakeup_reason == ESP_SLEEP_WAKEUP_GPIO) {
            Serial.println("Button Wake Detected — exiting sleep loop");
            menu = 0;
            device_mode = 0;

            displayClock(currentTime, formattedTimeArray[0], batteryPercentage, 0);

            // restart wifi
            Serial.println("Restarting Wifi...");
            restartWiFiAndServer();
            Serial.println("Restarting Wifi completed.");

            break;  // Exit the while(true)
          }

          Serial.println("Woke from timer — continuing slideshow");
        }
      }

      // sleep but show clock and update every minute
      else if (menu_selected_index == 1) {
        Serial.println("In Sleep Mode, displaying clock");
        while (true) {
          constexpr gpio_num_t WAKEUP_PIN = GPIO_NUM_26;        // button 1
          gpio_wakeup_enable(WAKEUP_PIN, GPIO_INTR_LOW_LEVEL);  // Trigger wake-up on high level

          esp_sleep_enable_gpio_wakeup();
          esp_sleep_enable_timer_wakeup(60 * uS_TO_S_FACTOR);

          // do clock here
          waitUntilTopOfMinute();  // waits till top then updates

          updateClock();

          displayClock(currentTime, formattedTimeArray[0], batteryPercentage, 1);

          // After waking
          esp_sleep_wakeup_cause_t wakeup_reason = esp_sleep_get_wakeup_cause();

          if (wakeup_reason == ESP_SLEEP_WAKEUP_GPIO) {
            Serial.println("Button Wake Detected — exiting sleep loop");
            menu = 0;
            device_mode = 0;

            displayClock(currentTime, formattedTimeArray[0], batteryPercentage, 0);

            // restart wifi
            Serial.println("Restarting Wifi...");
            restartWiFiAndServer();
            Serial.println("Restarting Wifi completed.");

            break;  // Exit the while(true)
          }
          Serial.println("Woke from timer — continuing clock");
        }
      }

      // hibernate and display current file until interrupt
      else if (menu_selected_index == 2) {
        Serial.println("In Hibernate Mode, displaying current image");
        while (true) {
          constexpr gpio_num_t WAKEUP_PIN = GPIO_NUM_26;        // button 1
          gpio_wakeup_enable(WAKEUP_PIN, GPIO_INTR_LOW_LEVEL);  // Trigger wake-up on high level
          esp_sleep_enable_gpio_wakeup();

          String current_file_location = String(DIRECTORY) + "/" + getCurrentFileName();
          app.currentFile = SD.open(current_file_location, FILE_READ);

          Serial.print("Displaying image: ");
          Serial.println(app.currentFileName);
          displayImageFromBin(app.currentFile);

          Serial.println("Turning off WiFi...");
          stopWifi();
          Serial.println("WiFi Disabled.");

          // sleep
          Serial.println("Now hibernating.");
          delay(500);
          esp_light_sleep_start();

          // After waking
          Serial.println("Woke up!");
          esp_sleep_wakeup_cause_t wakeup_reason = esp_sleep_get_wakeup_cause();

          // handle wakeup on GPIO
          if (wakeup_reason == ESP_SLEEP_WAKEUP_GPIO) {
            Serial.println("Button Wake Detected — exiting hibernation loop");
            menu = 0;
            device_mode = 0;

            displayClock(currentTime, formattedTimeArray[0], batteryPercentage, 0);

            // restart wifi
            Serial.println("Restarting Wifi...");
            restartWiFiAndServer();
            Serial.println("Restarting Wifi completed.");

            break;  // Exit the while(true)
          }
        }
      }
    }
  }
  app.resetButtons();
}

/* ========================== FUNCTION DEFINITION ========================== */
/* ===================== SERVER FUNCTIONS ===================== */
void handle_button_1() {
  Serial.printf("Printing Current File: %s [%d]\n", getCurrentFileName(), app.currentFileIndex);
  String current_file_location = String(DIRECTORY) + "/" + getCurrentFileName();
  app.currentFile = SD.open(current_file_location, FILE_READ);
  displayImageFromBin(app.currentFile);
}

//Initial page of the server web, list directory and give you the chance of deleting and uploading
void SD_dir() {
  if (app.sdPresent) {
    //Action according to post, download or delete, by MC 2022
    if (server.args() > 0)  //Arguments were received, ignored if there are not arguments
    {
      Serial.println(server.arg(0));

      String Order = server.arg(0);

      if (Order.indexOf("download_") >= 0) {
        Order.remove(0, 9);
        Order = String(DIRECTORY) + "/" + Order;

        SD_file_download(Order);
        Serial.print("'download_' Order (server.arg(0)): ");
        Serial.println(Order);
      }

      if ((server.arg(0)).indexOf("delete_") >= 0) {
        Order.remove(0, 7);
        Order = String(DIRECTORY) + "/" + Order;

        SD_file_delete(Order);
        Serial.print("'delete_' Order (server.arg(0)): ");
        Serial.println(Order);
      }
    }
    File root_server = SD.open(DIRECTORY);

    if (root_server) {
      root_server.rewindDirectory();
      SendHTML_Header();
      webpage += F("<table align='center'>");
      webpage += F("<tr><th>Name/Type</th><th>Type File/Dir</th><th>File Size</th><th>Download</th><th>Delete</th></tr>");
      printDirectory(DIRECTORY, 0);
      webpage += F("</table>");
      SendHTML_Content();
    } else {
      SendHTML_Header();
      webpage += F("<h3>No Files Found</h3>");
    }
    append_page_footer();
    SendHTML_Content();
    SendHTML_Stop();  //Stop is needed because no content length was sent
  } else ReportSDNotPresent();
}

//Prints the directory, it is called in void SD_dir()
void printDirectory(const char* dirname, uint8_t levels) {
  File root_server = SD.open(dirname);

  if (!root_server) {
    return;
  }
  if (!root_server.isDirectory()) {
    return;
  }
  File server_file = root_server.openNextFile();

  int i = 0;
  while (server_file) {
    if (webpage.length() > 1000) {
      SendHTML_Content();
    }
    if (server_file.isDirectory()) {
      webpage += "<tr><td>" + String(server_file.isDirectory() ? "Dir" : "File") + "</td><td>" + String(server_file.name()) + "</td><td></td></tr>";
      printDirectory(server_file.name(), levels - 1);
    } else {
      webpage += "<tr><td>" + String(server_file.name()) + "</td>";
      webpage += "<td>" + String(server_file.isDirectory() ? "Dir" : "File") + "</td>";
      int bytes = server_file.size();
      String fsize = "";
      if (bytes < 1024) fsize = String(bytes) + " B";
      else if (bytes < (1024 * 1024)) fsize = String(bytes / 1024.0, 3) + " KB";
      else if (bytes < (1024 * 1024 * 1024)) fsize = String(bytes / 1024.0 / 1024.0, 3) + " MB";
      else fsize = String(bytes / 1024.0 / 1024.0 / 1024.0, 3) + " GB";
      webpage += "<td>" + fsize + "</td>";
      webpage += "<td>";
      webpage += F("<FORM action='/' method='post'>");
      webpage += F("<button type='submit' name='download'");
      webpage += F("' value='");
      webpage += "download_" + String(server_file.name());
      webpage += F("'>Download</button>");
      webpage += "</td>";
      webpage += "<td>";
      webpage += F("<FORM action='/' method='post'>");
      webpage += F("<button type='submit' name='delete'");
      webpage += F("' value='");
      webpage += "delete_" + String(server_file.name());
      webpage += F("'>Delete</button>");
      webpage += "</td>";
      webpage += "</tr>";
    }
    server_file = root_server.openNextFile();
    i++;
  }
  server_file.close();
}

//Download a file from the SD, it is called in void SD_dir()
void SD_file_download(String filename) {
  if (app.sdPresent) {
    File download = SD.open(filename);
    if (download) {
      server.sendHeader("Content-Type", "text/text");
      server.sendHeader("Content-Disposition", "attachment; filename=" + filename);
      server.sendHeader("Connection", "close");
      server.streamFile(download, "application/octet-stream");
      download.close();
    } else ReportFileNotPresent("download");
  } else ReportSDNotPresent();
}
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

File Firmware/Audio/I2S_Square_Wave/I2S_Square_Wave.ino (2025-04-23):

#include <driver/i2s.h>

static const i2s_port_t i2s_num = I2S_NUM_0; // i2s port number

// Config I2S

static const i2s_config_t i2s_config = {
    .mode = (i2s_mode_t) (I2S_MODE_MASTER | I2S_MODE_TX),
    .sample_rate = 44100,
    .bits_per_sample = I2S_BITS_PER_SAMPLE_16BIT,
    .channel_format = I2S_CHANNEL_FMT_RIGHT_LEFT,
    .communication_format = (i2s_comm_format_t) (I2S_COMM_FORMAT_STAND_I2S | I2S_COMM_FORMAT_STAND_MSB),
    .intr_alloc_flags = ESP_INTR_FLAG_LEVEL1, // default interrupt priority
    .dma_buf_count = 8,
    .dma_buf_len = 1024,
    .use_apll = 0,
    .tx_desc_auto_clear = true,
    .fixed_mclk = -1
};

static const i2s_pin_config_t pin_config = {
  .bck_io_num = 27,
  .ws_io_num = 26,
  .data_out_num = 25,
  .data_in_num = I2S_PIN_NO_CHANGE
};



void setup() {
  // put your setup code here, to run once:
  i2s_driver_install(i2s_num, &i2s_config, 0, NULL);
  i2s_set_pin(i2s_num, &pin_config);
}

void loop() {
  // put your main code here, to run repeatedly:
    // This code generates a square wave, the frequency is changed by changing the WaveLength var below, the higher the
  // number the lower the frequency. This var simply acts as a timer for how long we stay high (peak) and low (trough)

  static const uint16_t Volume=0x3ff;             // Highest value the peak will get to, bigger gives louder vol, but  
                                                  // too high can lead to distortion on cheap or small speakers
  static const int16_t Peak=Volume;               // Max height/peak  
  static const int16_t Trough=-Volume;            // Max low/trough
  
  static int16_t OutputValue=Peak;                // Value to send to each channel (left/right), start off at the peak
  static const uint16_t WaveLength=100;           // Bigger =longer wavelength and higher frequency
  static uint16_t TimeAtPeakOrTrough=WaveLength;  // Var to count down how long we hold at either peak or trough
                                                  // (high/low)
  uint32_t Value32Bit;                            // This holds the value we actually send to the I2S buffers, it basically
                                                  // will hold the "OutputValue" but combined for both left/right channels
                                                  
  size_t BytesWritten;                            // Returned by the I2S write routine, we are not interested in it but
                                                  // must supply it as a param to the routine.
                                                    
  if(TimeAtPeakOrTrough==0)                       // If 0 then we're ready to switch to a peak (high) or trough (low)
  {
    if(OutputValue==Peak)                         // If we were a peak (high), switch to trough (low) value
        OutputValue=Trough;
    else                                          // else we were a trough (low) switch to peak (high)
        OutputValue=Peak;
    TimeAtPeakOrTrough=WaveLength;                // Reset this counter back to max, ready to countdown again
  }
  TimeAtPeakOrTrough--;                           // Decrement this counter that controls wavelenght/ frequency

  // This next line just creates the 32 bit word we send to the I2S interface/buffers. 16 bits for the righ channel
  // and 16 bits for the left, as we are sending the same wave to both channels we just combine them using some
  // bit shifting and masking. If you're not sure what's happening here then look up bit shifting/ manipulation
  // on a C programming website.
  
  Value32Bit = (OutputValue<<16) | (OutputValue & 0xffff); // Output same value on both left and right channels

  // Output the combined 32bit value, will not return from this routine until written (blocks your code). Look
  // up this function for further info  
  i2s_write(i2s_num,&Value32Bit,4,&BytesWritten,portMAX_DELAY ); 
}

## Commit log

2025-05-13 Add SD Wireless Upload
2025-05-18 Modularized Web Helpers, also added 4th button reverse
    [full_disp_AND_upload.ino]
2025-05-18 Rearranged Buttons + Made some Beautification
2025-05-29 Added Clock Display (Battery, Date, Time, Annotations) and Hold Button Functionality - STill need to fix battery percentage bar
    [full_disp_AND_upload.ino]
2025-06-03 Add PCB
    [3.3vBBConverter.kicad_sch, ESP32_Clock_Gallery.kicad_pcb, ESP32_Clock_Gallery.kicad_sch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]
2025-06-08 PCB Routing
    [1984617.step, 3.3vBBConverter.kicad_sch, B8B-PH-K-S_LF__SN_.step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]
2025-07-18 Schematic PDF
